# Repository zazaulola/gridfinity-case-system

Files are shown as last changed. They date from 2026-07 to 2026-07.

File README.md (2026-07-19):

# Gridfinity Case System

A fork of [smkent/monoscad](https://github.com/smkent/monoscad) focused on
the [Gridfinity Rugged Storage Box](gridfinity/rugged-box/): a stackable,
latching, parametric OpenSCAD case system for Gridfinity bins, extended
into a complete carry system rated for **~5 kg per case and 15-25 kg per
stack**.

Demo animation

*One-turn overview → lid opens → two layers of bins and a removable level
tray go in → a second case stacks below and locks → the split lid handle
rises into its self-clamping X-arch and lifts the stack.*

## Fork additions

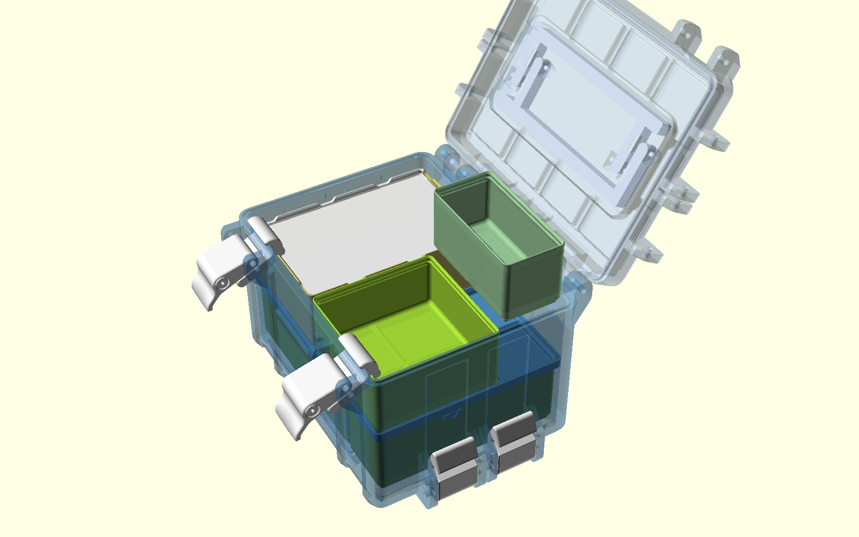
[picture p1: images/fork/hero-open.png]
Open case with bins


* **Lid carry handle** recessed into the center of the lid — folded, it
  stays below the stacking plane, so cases still stack and latch on top.
  Two styles: a single fold-flat bail, or the **split X-arch** (two
  identical half-bails on central axes whose grip bars press together
  under load; four pivots, level carry on every case size).
* **Heavy-duty attachments**: M4 screws with enlarged eyelets and latch
  bodies, a third hinge from 3 units wide, and optional stacking latches
  at every grid boundary.
* **Removable level tray**: a baseplate tray with Gridfinity feet that
  turns bin layers into liftable levels; fold-flat pull bails hide below
  the bin seating plane, all-printed pivots.
* **Hardware-friendly options**: hex nut pockets (screws clamp with nuts,
  no thread-forming); **axle sleeves** — printed 8 mm bearing sleeves
  retained by two short M4x12..20 screws, so no screws longer than 20 mm
  are needed anywhere and rotating parts never ride on threads.
* **Silicone cord seal**: a dovetail groove in the bottom lip for 2-4 mm
  cord, with snap-in retention and self-limited ~25% compression.
* **Bins**: plain stackable bins and sliding-lid bins (from
  [gridfinity/lid-bins](gridfinity/lid-bins/)) compose with the cases;
  equal-height bins act as a baseplate for the next layer.

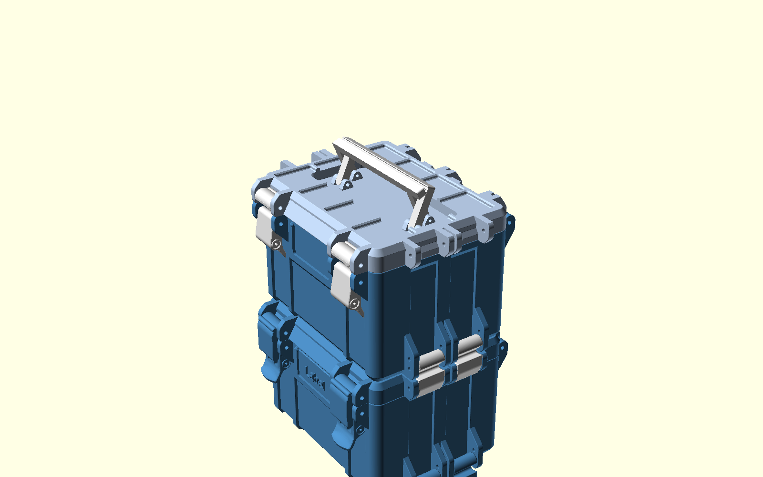
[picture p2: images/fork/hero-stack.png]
Stacked cases with raised handle

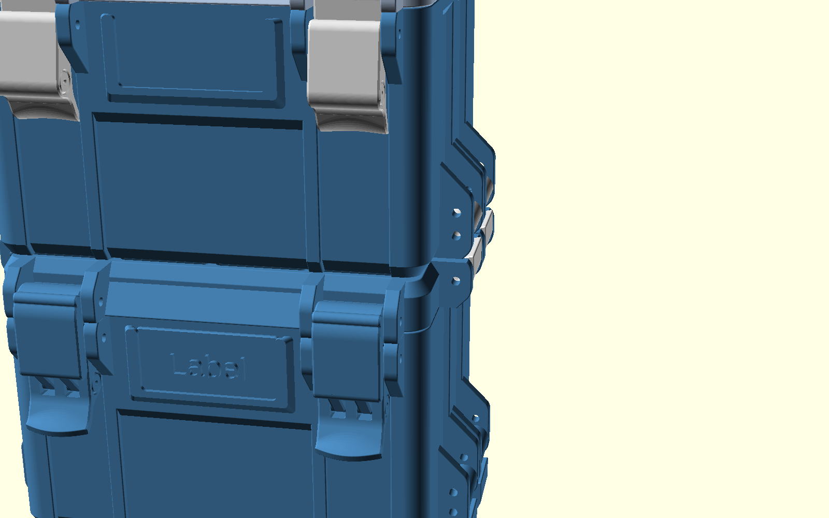
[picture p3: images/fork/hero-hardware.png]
Stacking hardware


See [gridfinity/rugged-box/README.md](gridfinity/rugged-box/README.md) for
option documentation, load-path rationale, hardware lists, and print
guidance. A full pre-rendered STL kit for 260mm printers (5x5 case, 90
bins, 90 lidded bins, level tray) is generated under
`gridfinity/rugged-box/build/` (see the manifest there; the video is
`images/fork/demo.mp4`).

---

# My OpenSCAD models for 3D printing

[bulbasaur0 on Printables][printables-profile]

A monorepository for my [OpenSCAD][openscad] models and remixes. Print-ready
models are also [published on Printables][printables-profile].

## Setup

Models in this repository depend on various
[third-party libraries][openscad-libraries], which are provided as
[git submodules][git-submodules] using
[smkent/openscad-libraries][smkent-openscad-libraries].

After cloning this repository, install all third-party libraries by running in
the repository directory:

```console
git submodule update --init --recursive
```

## Rendering models via CLI

Each model has preconfigured renders to be created via the
[OpenSCAD CLI][openscad-cli] using [SCons][scons].
Model STL files published to Printables are rendered this way.

SCons is a Python package and can be installed using `pip`:

```console
pip install --user scons
```

To build the configured model renders for a particular model, change to the
desired model directory and run:

```console
scons -u
```

Rendered models will be placed in a `build` subdirectory within the model
directory.

## Model samples

Click an image to view the corresponding model, or browse subdirectories for all
models.

Gridfinity Rugged Storage Box, Parametric and Customizable
Rugged Storage Box
Gridfinity Bins with Lids (parametric remix)
Segmented Modular Hose
Drill bit clips for Bosch Custom Case / Pick and Click
SG-1 Stargate

## License

### Models

Each model in this repository is licensed individually, especially for remixes
which must maintain compatible licensing with their original model(s).

See `README.md` and/or any `LICENSE` files within a model's subdirectory for
that model's license.

### Third party libraries

Third party libraries have their own licenses.

### Monorepository

All remaining contents of this repository (i.e. not models or third party
libraries) are licensed under [Creative Commons (4.0 International License)
Attribution][license-cc-by-4.0].

[git-submodules]: https://git-scm.com/book/en/v2/Git-Tools-Submodules
[license-cc-by-4.0]: http://creativecommons.org/licenses/by/4.0/
[openscad-cli]: https://en.wikibooks.org/wiki/OpenSCAD_User_Manual/Using_OpenSCAD_in_a_command_line_environment
[openscad-libraries]: https://en.wikibooks.org/wiki/OpenSCAD_User_Manual/Libraries
[openscad]: https://openscad.org
[printables-profile-badge]: /_static/printables-profile-badge.svg
[printables-profile]: https://www.printables.com/@bulbasaur0/models
[scons]: https://scons.org/
[smkent-openscad-libraries]: https://github.com/smkent/openscad-libraries

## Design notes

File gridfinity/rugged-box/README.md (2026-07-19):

# Gridfinity Rugged Storage Box, Parametric and Customizable

[Available on Printables][printables-model]
[CC-BY-SA-4.0 license][license]

A Gridfinity compatible parametric and customizable rugged storage box or
toolbox for OpenSCAD. Make and customize your own boxes!

Renders animation showing various box sizes

# Description

My [Rugged Storage Box][rugged-box-base-model], now for [Gridfinity][gridfinity]
bins!

Inspired by
[several][rugged-gridfinity-box-by-pjotrstrong]
[other][gridfinity-storage-box-by-pred]
[terrific][gridbox-by-bilbodd]
[Gridfinity][fully-printable-gridfinity-box-by-lennard-hoting]
[box][rugged-gridfinity-box-by-peterdesigns]
[models][rugged-gridfinity-box-lid-insert-by-zanfar],
I built a Gridfinity rugged box model of my own! This is a parametric model
which can create boxes of any size. I chose [OpenSCAD][openscad] so the software
and model would be fully open source.

## Features

Photo of stacked boxes
Photo of open boxes

Photo of open box with lid plate caption
Photo of box side with latch captions

Clip of box opening/closing
Clip of box stacking latches usage

Gridfinity:

* Configurable sizing in Gridfinity grid units
* Optional exterior stacking grid on top/bottom of box

Box options:

* Choice of latch style (clip or draw)
* Side stacking latches
* Optional handle
* Optional label
* Top opening grip and hinge end stops
* Lip seal: integrated, for 1.75mm filament, or a dovetail groove for
  silicone cord (fork addition)
* Reinforced (thicker) corners
* Optional third hinge for large boxes

## Fork additions: lid carry handle and heavy-duty attachments

This fork extends the original model with a stack-friendly carry handle in
the lid and reinforced attachments, targeting transport of a stack of loaded
boxes (up to ~5 kg per box, ~15-25 kg per stack of 3-5 boxes) carried by the
top box's lid handle.

### Lid carry handle (`Lid_Handle`, default on)

A fold-flat carry bail recessed into a pocket in the center of the lid:

* The folded bail and its pivot bosses stay at least 1 mm below the plane of
  the Gridfinity feet of a box stacked on top, so **boxes still stack and
  latch normally with the handle installed**.
* The pivot axis is a pair of **M3x20** screws in double shear through
  printed bosses, so the carrying load is carried by steel, not by printed
  hinge pins. The lid handle always uses M3 pivots regardless of the
  `Heavy_Duty` setting.
* A sloped finger scoop ahead of the folded grip bar provides access to lift
  the bail; when raised, there is ~32 mm of finger clearance between the
  grip and the lid surface.
* Requires a box at least 3 Gridfinity units wide and a top at least
  2 units tall. On boxes 2-3 units long the pivot axis is offset from the
  lid center (the pocket cannot be centered around it; ~29 mm at 2 units,
  ~8 mm at 3 units), so a single box hangs with a slight tilt; stacks hang
  nearly level. On boxes 4+ units long the axis is centered and the box
  hangs level.
* Print the `lid_handle` part flat as oriented; layers run along the bail
  plane, which loads the layer lines in tension/bending within the plane.
* Assembly: place the bail eyelets between the boss pairs and drive the two
  M3x20 screws outward from the pocket center with a long (ball-end) hex
  key. The screws thread into the outer bosses.

The handle load path is: bail (steel pivot screws) → lid pocket housing →
lid hinges and latches → box body → side stacking latches → next box below.
The weakest links are the printed latch and hinge parts, which is what the
heavy-duty option reinforces.

#### Split style (`Lid_Handle_Style` = "split")

An alternative handle: two point-symmetric half-bails (the same printed
part twice) on parallel axes 18 mm apart at the lid center. They fold
inward past each other — the arms are interleaved into separate lanes —
and rise to a **self-clamping X-arch**: under load, arm tension presses
the two grip bars together, so the arch needs no latch. Compared to the
single bail:

* Four M3 pivots share the carry load (half the per-pivot cyclic load).
* The pocket is symmetric and shorter (~63 mm vs ~72 mm) and 1 mm
  shallower, preserving more of the lid stacking grid.
* The pivot axes are centered on every box size, so a carried box hangs
  level even at 2 units long (the single bail is offset there).
* No finger scoop: raise the handle by dragging both textured bars
  toward the center with two fingertips, then grip the met pair
  (~27 mm above the lid; fingers curl into the arch and the open pocket).
* Hardware: 4x M3x18..20.

### Heavy-duty attachments (`Heavy_Duty`, default on)

* All hinge, latch, and stacking latch screws move from **M3 to M4**, and
  the printed screw eyelets and latch bodies scale up accordingly
  (`screw_eyelet_size_proportion` and `latch_body_size_proportion`
  3.0 → 3.4). Latches hook over the exposed steel screw shanks, so shear
  goes through steel; the enlarged printed eyelets reduce bearing stress at
  roughly 5 MPa or less per attachment at the target loads (PETG yields at
  ~50 MPa; short-term carrying loads leave a comfortable margin for creep
  and shock).
* The optional third (center) hinge now engages on boxes **3+ units wide**
  (previously 5+).
* With the default `Latch_Width` 28 and `Rib_Width` 6, attachment screws are
  **M4x40** (`28 + 2 * 6 = 40`); check the console output (BOM echo) for the
  exact count and length for your configuration. Set `Heavy_Duty` to false
  to keep the original M3 sizing.
* For even thicker ribs, raise `Rib_Width` together with `Latch_Width`: the
  paired top hinge requires `Latch_Width > 4 * Rib_Width + 0.6` (for
  example, `Rib_Width` 8 with `Latch_Width` 34 and M4x50 screws). Raising
  `Rib_Width` alone silently degrades the top hinge to a single narrow
  eyelet.

### Hex nut pockets (`Nut_Pockets`, default off)

Cuts DIN 934 hex nut pockets into the outward faces of the attachment ribs
(latches, stacking latches, and both outer faces of the bottom hinge ribs)
and enlarges every attachment screw hole to clearance fit. One nut per
screw. Benefits:

* Hinge screws become nut-clamped hinge pins: opening and closing the lid
  cannot rotate or back the screw out of formed plastic threads. (Without
  this option the tight fit in the bottom hinge ribs is intentional — the
  screw thread-forms there and stays fixed while the lid's loose eyelet
  rotates on the shank; if your printed lid eyelet is also tight, ream it
  to ~4.2-4.5 mm for M4.)
* Threads no longer wear with repeated disassembly.
* Cut lengths of M4 threaded rod can substitute for screws.

Cap screw heads (7 mm across) partially recess into the pockets on the
head side as a bonus. Nut pockets and screw length: the stock length still
works — the nut sits inside the pocket flush with the rib face.

### Axle sleeves: short common screws only (`Axle_Sleeves`, default off)

Replaces every long M4x40 through screw with a printed **8 mm bearing
sleeve** spanning between the attachment ribs, retained by two short
**M4x12..20** screws driven into its bore from the rib outer faces —
lengths every hardware kit already contains. Benefits:

* No screws longer than 20 mm anywhere in the box (the lid handle already
  uses M3x20 and the level tray is all-printed).
* Latches and hinges rotate on the smooth sleeve surface instead of screw
  threads: far larger bearing area, no thread abrasion of the plastic
  bores, and the sleeve is a cheap replaceable wear part.
* An 8 mm round brass standoff with M4 threads (female-female) is a
  drop-in metal substitute for the printed sleeve.

Print the `axle_sleeve` part set (sleeve counts and both lengths are
echoed to the console). Latch, stacking latch, hinge, and handle bores
grow to ride the sleeve, so render **all** parts with the option enabled —
sleeve-mode latches do not fit a non-sleeve box. Requires `Heavy_Duty`
(M4 sizing); the front `Handle` option still uses long screws.

### Silicone cord seal (`Lip_Seal_Type` = "silicone")

A dovetail cord groove in the bottom lip for standard silicone cord
(`Silicone_Cord_Diameter` 2..4 mm, default 3):

* Groove depth is 0.75x the cord diameter, so the flat top lip compresses
  the cord by up to ~25% at full closure, self-limited by lip contact.
* The dovetail mouth (0.95x cord) snaps the cord in and retains it when
  the box is open; the groove cross-section exceeds the cord area so the
  incompressible silicone has room to spread.
* Use **soft** cord (40..60 ShA); harder cord raises the latch closing
  force noticeably on large boxes. The required cord length is echoed to
  the console (BOM). Join the ends with a straight butt cut and a drop of
  cyanoacrylate, placed mid-wall on the hinge side.
* The top part is unchanged — the option only alters the bottom, and
  works with any other option combination.

### Stacking latch density (`Stacking_Latch_Density`)

For heavy stacks, `max` places one stacking latch at every interior
Gridfinity cell boundary on each side (a 4-unit-long box gets 3 per side
instead of 2). These positions are a superset of the standard ones, so
boxes with mixed density settings still latch to each other when
grid-aligned; for boxes 2-3 units long, `max` equals `standard`. This
option requires `Latch_Width + 2 * Rib_Width` ≤ 40 mm (satisfied by the
defaults, 28 + 2 × 6 = 40) so adjacent latches do not overlap. The default
`standard` keeps the original placement.

### Other default changes in this fork

* The front `Handle` option now defaults to **false** (the lid handle is the
  primary carry); enable it in the customizer if you want both.
* `Third_Hinge` and `Lid_Handle` default to true, `Heavy_Duty` defaults to
  true.

### Removable level tray (`level-tray.scad`)

A companion model: a removable tray whose top face copies the box floor
baseplate and whose underside has Gridfinity feet, so it registers on the
box floor or on a layer of equal-height bins — building removable levels
of bins inside the box. Two fold-flat pull bails recessed into deepened
wells at two edge cells allow lifting the whole level out; folded, the
bails stay below the bin seating plane, so every cell remains usable
(remove the two bins over the wells to raise the bails). Fully printed:
the bails pivot on printed 3 mm axle pins inserted from the tray edge
faces; inside the box, the box walls keep the pins captive. Set `Width`
and `Length` to the box size; parts: `tray`, `pull_bail` (x2),
`axle_pin` (x2).

### Print recommendations for load-rated boxes

* Material: PETG or ASA (better creep and impact behavior than PLA;
  PLA is acceptable for light duty).
* Walls: 4+ perimeters; infill 30%+ (gyroid or grid).
* Use the `top_modifier`/`bottom_modifier` volumes to locally raise infill
  and perimeters around the attachment ribs (see "Reinforcing the box
  attachment ribs" below). The lid handle pocket housing is included in the
  top modifier volume.
* Latches, stacking latches, and the lid handle print in their default
  orientation; do not rotate them, their strength depends on layer
  direction.

## Hardware and Tools

**Fork note:** with this fork's default `Heavy_Duty = true`, the hinges and
latches use **M4** screws — **M4x40** hex socket head cap screws (DIN 912)
at the default `Latch_Width` 28 / `Rib_Width` 6, driven with a 3 mm hex key.
The lid handle additionally takes 2x **M3x20**. The console output (BOM
echo) prints the exact screw count and length for your configuration. The
rest of this section describes the original M3 sizing, which applies when
`Heavy_Duty` is false.

The hinges and latches are attached using M3 screws, **M3x40** by default.
Depending on whether a handle or stacking latches are desired, a box may take
between 6 and 25 screws to assemble.

My boxes are assembled using M3x40 and M3x55 hex socket head cap screws
(DIN 912):

* M3x40 ([AliExpress 1][m3x40-aliexpress-1], [AliExpress 2][m3x40-aliexpress-2],
  [Amazon][m3x40-amazon], [Trimcraft Aviation RC][m3x40-trimcraftaviationrc])
* M3x55 ([AliExpress][m3x55-aliexpress], [Amazon][m3x55-amazon])
  -- if attaching the optional handle

To assemble boxes with three stacking latches per side and/or a third hinge, a
hex allen key matching your screws is needed since a drill/driver won't fit. M3
hex socket head cap screws use 2.5mm drive, so a ~6" 2.5mm hex allen key is
needed for these
([Home Depot][2.5mm-hex-allen-key-hd], [Amazon][2.5mm-hex-allen-key-amazon]).

### Screw length formula

* All screws except for boxes with handles:
  * `Latch Width` (default 28mm) + 2 x `Rib Width` (default 6mm).
    At default values, `28 + 2 * 6 = 40`, or M3x40 screws.
  * To use M3x30 screws, set `Latch Width` to 22 and `Rib Width` to 4.

* For boxes with handles, replace two of the above screws with:
  * `Latch Width` (default 28mm) + 3 x `Rib Width` (default 6mm) + handle
    thickness (10mm).
    At default values, `28 + 3 * 6 + 10 = 56`, or about M3x55 screws.

## Rendering

### OpenSCAD version and configuration

Two OpenSCAD options are available which greatly improve rendering speed, but
are currently only in the development snapshots. You can download a development
snapshot from [the OpenSCAD downloads page][openscad-download] (scroll down
about half way).

After installation, open **Edit** > **Preferences**, and in **Features**,
enable:

* fast-csg
* fast-csg-safer
* manifold

OpenSCAD features screenshot

### Model setup

See [the top-level README.md](/README.md) for libraries installation.

### Model rendering

Ensure both `rugged-box-gridfinity.scad` and `rugged-box-library.scad` are
placed in the same directory. Open `rugged-box-gridfinity.scad` in OpenSCAD.

Select your desired dimensions and options in the OpenSCAD Customizer. Then, one
at a time, select each part (top, bottom, latch, stacking latch, handle, lid
handle) in the
Part drop-down. For each part, perform a render (F6) and export to STL (F7).

Customizer screenshot
Customizer part selection screenshot

### Recommended model configuration

*tl;dr:*

* Box parts with different **Gridfinity Stackable** settings are not compatible.
  Print all your box parts with this value enabled or disabled, not a mix of
  both.
* Set **Top Height** to 2
* Set **Bottom Height** to 4, 7, or 10 for a 6, 9, or 12 Gridfinity unit tall
  box, respectively
* To use stacking latches, boxes must have the same **Width** and a multiple of
  2 for **Length**
* Use **draw** latches for boxes 9 or more units tall, or **clip** latches for
  shorter boxes

Boxes with the **Gridfinity Stackable** option modify the placement of the
internal Gridfinity baseplate and top bases to accomodate the exterior stacking
base and baseplate. Therefore both the top and bottom of the box must be printed
with the same value for this option; do not mix and match. Additionally,
stacking latches will not reach the correct height between the two types of
boxes.

I recommend keeping most of the box height in the bottom, so Gridfinity bins
will be more contained in the box when the lid is open. I render my box tops
with **Top Height** set to **2** (7mm Gridfinity units).

Most of my Gridfinity bins are multiples of 3 units high (e.g. 3 or 6). I
therefore like to print boxes that are multiples of 3 units high. For a total
box height at a multiple of 3, I set **Bottom Height** to the desired box height
minus my **Top Height** of 2. For example, to make a box that is 9 total
Gridfinity units tall, I set **Top Height** to **2** and **Bottom Height** to
**7**.

If using the stacking latches feature, boxes will stack if they are the same
**Width** (left to right) and have stacking latch attachments at consistent lengths
on the side. To produce boxes with consistent attachment points, set **Length**
(front to back) to a multiple of 2 Gridfinity units. For example, a 6 unit wide
and 4 unit long box can use stacking latches with another box of the same size,
or with a 6 unit wide and 6 unit long box.

Front latches: I prefer draw latches but they are taller, so clip latches are also
available. I recommend using draw latches for boxes with a total height of 9
Gridfinity units or more. Smaller boxes should use clip latches.

Larger boxes use more filament, but result in more storage space per amount of
filament and time spent to print.

## Printing

### Printer preparation

These boxes are (usually) large prints. Clean your print bed and ensure it is
reasonably level.

### General print settings

The following instructions are for slicing with PrusaSlicer.

My boxes are printed in PETG at 0.24mm layer height, with 2 perimeters and 20%
adaptive cubic infill. I printed my latches and handle at 0.2mm layer height,
with 3 perimeters and 30% adaptive cubic infill.

Print the box top and bottom parts on their outer faces. Latches print on their
side. For the latches, a brim may be helpful for bed adhesion.

For boxes without exterior Gridfinity stacking (**Gridfinity Stackable** model
option), the box tops and bottoms print without supports.

Slicer screenshot with plain box

For boxes with exterior Gridfinity stacking, see
["Additional print settings for Gridfinity Stackable boxes"](#additional-print-settings-for-gridfinity-stackable-boxes)
below.

#### Reinforcing the box attachment ribs

PrusaSlicer can configure this model to use a higher infill on specific parts,
such as the attachment ribs (where screws are installed). The model includes
optional modifier volumes to make this simple.

To render a modifier volume in the OpenSCAD model, open and configure the box
model the same as the box model you'd like to print. Then, in the **Part**
drop-down, select and render each of:

* Top print modifier volume for attachment ribs
* Bottom print modifier volume for attachment ribs

This will produce a model that is just the attachment ribs without the box body.
Render and export each of these models.

OpenSCAD screenshot of modifier part selected

In PrusaSlicer, load the box model to print. Then, in the Plater view,
right-click on the box model to open the context menu. Select **Add Modifier**
-> **Load...**, and then select the modifier volume for the matching part
(bottom/top). The modifier volume should perfectly overlap with the existing
model.

Finally, locate the added modifier volume model in the right sidebar next to the
Plater view. Right-click on the modifier volume, and select **Infill** to
override the infill settings for that volume. Then, enter your desired infill
percentage for the ribs (e.g. 100%).

Now the model is configured to slice the ribs with 100% infill!

PrusaSlicer modifier steps animation

### Additional print settings for Gridfinity Stackable boxes

Boxes with the **Gridfinity Stackable** model option require supports and
additional settings to print for both the box top and bottom.

#### Box top

The box top prints upside down. Supports are needed for each grid of the
integrated Gridfinity baseplate.

Slicer screenshot of stackable box top

OpenSCAD renders the exterior stacking grid on the box top with some errant
zero-thickness polygons that make manually painting supports difficult. (These
don't affect the printed box.)

With the support painting tool (hotkey **L**):

* Next to the **Highlight overhang by angle** value, click the edit button and
  enter **1**.
* Click **Enforce** to automatically paint supports.

Slicer screenshot of stackable box top, support application

This method paints the integrated Gridfinity baseplate, and additionally the
very top overhang on all the screw holes with supports. The screw hole overhangs
do not need supports, so these should be removed. With the support painting tool
still selected:

* Uncheck **Split triangles** near the bottom of the paint settings. This will
  speed up the manual (un-)painting process
* **Shift+Left-click** on each of the inner screw hole overhang polygons to
  remove the painted supports from the screw holes

Slicer screenshot of stackable box top, supports applied
Slicer screenshot of stackable box top, overhang supports to remove

Finally, configure these print settings for the box top:

* Enable **Support material > Generate support material** (Enable supports)
* Disable **Support material > Auto-generated supports** (Add supports only to
  the painted areas)
* Set **Support material > Style** to **Snug**. Organic supports use more
  material and require longer to print.
* Set **Support material > Pattern spacing** to **5**. This decreases the amount
  of support material used.
* Set **Support material > XY separation between and object and its support** to
  **4**. This ensures a border between the support bases and gridfinity base
  square edges for easier support removal.
* Set **Infill > Bridging angle** to **135**. This sets the first Gridfinity
  baseplate layer visible on the box top to print at an angle, for a better
  finished look. Avoid setting this to 45, as that causes the first and second
  model layers to be printed at the same angle which is undesirable.

Slicer screenshot of stackable box top, ready to print

#### Box bottom

The box bottom prints upright. Supports are needed for the outer perimeter
that overhangs the base Gridfinity grid.

Slicer screenshot of stackable box bottom

With the support painting tool (hotkey **L**):

* Uncheck **Split triangles** near the bottom of the paint settings. This will
  speed up the manual painting process.
* Set **Brush size** to a small value, such as **0.5**. This will make the
  painting process easier.
* Rotate the model so the underside is visible.
* **Left-click** to paint supports on the outer perimeter that overhangs the
  base Gridfinity grid.

Slicer screenshot of stackable box bottom, with painted supports

Finally, configure these print settings for the box bottom:

* Enable **Support material > Generate support material** (Enable supports)
* Disable **Support material > Auto-generated supports** (Add supports only to
  the painted areas)
* Set **Support material > Style** to **Snug**. Organic supports use more
  material and require longer to print.
* Set **Support material > Pattern angle** to **45** (or 135). By default, snug
  supports print in straight horizontal lines which would result in very long
  single lines drawn around two of the box sides. Setting this to 45 or 135
  causes the support pattern to be properly staggered around the entire box.
* Set **Infill > Bridging angle** to **135**. This sets the first box body layer
  on the underside of the main box body to print at an angle, for a better
  finished look. Avoid setting this to 45, as that causes the first and parts of
  the second model layers to be printed at the same angle which is undesirable.

If you are reconfiguring your slicer after preparing the box top, restore these
settings to their default values:

* **Support material > Pattern spacing** (default 2mm).
* **Support material > XY separation between and object and its support**
  (default 60%).

Slicer screenshot of stackable box bottom, ready to print

## Assembly

**Important**: Don't overdrive the screws into the screw holes. They just need
to be attached to fasten the hinges and latches, and for the latches to clip on
to when the box is closed.

Place the box top onto the box bottom, and install screws into the hinges.

Attach the front and side stacking latches with additional screws. If attaching
a handle to the front, use two longer screws for the front latch screw on the
bottom in order to attach the handle.

**Note**: For large boxes with a three stacking latches per side and/or the
optional third hinge, install the center hinge/latch screws first with a hex
allen key before installing the remaining hinge/latch screws.

Photo of middle hinge/latch screw installation

## Enjoy!

I had a lot of fun creating this model. Please share your feedback and makes!

## Differences of the remix compared to the original

This uses [Gridfinity Rebuilt in OpenSCAD][gridfinity-rebuilt-openscad] to add
[Gridfinity][gridfinity]-compatible baseplates and stacking covers to my
[Rugged Storage Box][rugged-box-base-model].

## Attribution and License

This model is licensed under [Creative Commons (4.0 International License) Attribution-ShareAlike][license].

This is a remix of
[**Gridfinity Rebuilt in OpenSCAD** by **kennetek**][gridfinity-rebuilt-openscad].

[Gridfinity][gridfinity] and
[Gridfinity Rebuilt in OpenSCAD][gridfinity-rebuilt-openscad]
use the [MIT License][gridfinity-license].

[2.5mm-hex-allen-key-amazon]: https://amazon.com/dp/B005G2RMLM
[2.5mm-hex-allen-key-hd]: https://www.homedepot.com/p/203195203
[fully-printable-gridfinity-box-by-lennard-hoting]: https://www.printables.com/model/369813-fully-printable-gridfinity-box-parametric
[gridbox-by-bilbodd]: https://www.printables.com/model/325677-gridbox
[gridfinity-license]: LICENSE.gridfinity
[gridfinity-rebuilt-openscad]: https://github.com/kennetek/gridfinity-rebuilt-openscad
[gridfinity-storage-box-by-pred]: https://www.printables.com/model/543553-gridfinity-storage-box-by-pred-now-parametric
[gridfinity]: https://www.youtube.com/watch?v=ra_9zU-mnl8
[license-badge]: /_static/license-badge-cc-by-sa-4.0.svg
[license]: http://creativecommons.org/licenses/by-sa/4.0/
[m3x40-aliexpress-1]: https://www.aliexpress.us/item/3256805665122576.html
[m3x40-aliexpress-2]: https://www.aliexpress.us/item/2251832624557792.html
[m3x40-amazon]: https://amazon.com/dp/B0CFQN9P7Y/
[m3x40-trimcraftaviationrc]: https://www.trimcraftaviationrc.com/index.php?route=product/product&product_id=481
[m3x55-aliexpress]: https://www.aliexpress.us/item/3256802885431338.html
[m3x55-amazon]: https://amazon.com/dp/B0BGM9N73R/
[openscad-download]: https://openscad.org/downloads.html
[openscad]: https://openscad.org
[printables-badge]: /_static/printables-badge.png
[printables-model]: https://www.printables.com/model/757297
[rugged-box-base-model]: ../../rugged-box/
[rugged-gridfinity-box-by-peterdesigns]: https://www.printables.com/model/495142-rugged-gridfinity-box-parametric
[rugged-gridfinity-box-by-pjotrstrong]: https://www.printables.com/model/361829-rugged-gridfinity-box
[rugged-gridfinity-box-lid-insert-by-zanfar]: https://www.printables.com/model/491142-rugged-gridfinity-box-lid-insert

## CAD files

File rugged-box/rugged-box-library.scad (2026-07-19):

/*
 * Customizable and Parametric Rugged Storage Box
 * By smkent (GitHub) / bulbasaur0 (Printables)
 *
 * Rugged storage box library
 *
 * Licensed under Creative Commons (4.0 International License) Attribution-ShareAlike
 */

module __end_customizer_options__() { }

// Constants

$fa = $preview ? $fa : 2;
$fs = $preview ? $fs / 2 : 0.2;

// Attachment screw diameter
screw_diameter = 3; // M3

// Decrease screw hole diameter just slightly for better thread-forming fit
screw_hole_diameter_size_tolerance = -0.1;

// Hex nut pocket fit added to the nut width across flats
nut_pocket_width_tolerance = 0.35;
// Extra pocket depth beyond the nut height
nut_pocket_depth_tolerance = 0.4;

// Axle sleeve outer diameter: a printed (or brass standoff) bearing sleeve
// spanning between the attachment ribs. Rotating parts ride the smooth
// sleeve surface, and the sleeve is retained by two short screws driven
// into its bore from the rib outer faces, replacing the long through screw
axle_sleeve_diameter = 8;
// Diametral running fit for parts rotating on the sleeve
axle_sleeve_fit = 0.4;
// Snug fit for latch catch slots hooking over the sleeve
axle_sleeve_catch_fit = 0.2;

// Widen angle of box plain ribs
plain_ribs_angle = 8;

// Extra space between box body and hinge for clearance
hinge_extra_setback = 0.2; // [0:0.1:2]
hinge_size_tolerance = 0.1;

// Box top hinge screw eyelet position fit tolerance adjustment
top_hinge_eyelet_position_tolerance = 0.1;

// Screw eyelet diameter as a proportion of screw diameter
screw_eyelet_size_proportion = 3.0; // [1.5:0.1:5]

// Depth and maximum width of lip grip
top_grip_depth = 6;
top_grip_width = 100;

// Latch size
latch_edge_radius = 0.8;
latch_body_size_proportion = 3.0; // [1.5:0.1:5]

// Stacking latch size
stacking_latch_catch_offset = -10;
stacking_latch_grip_length = 8;
stacking_latch_screw_separation = 20;

// Handle size
handle_thickness = 10;
handle_min_height = 16;
handle_max_height = 35;
handle_radius = 5;

// Lid handle size
// The lid handle pivots always use M3 screws, independent of the main
// attachment screw size, so the folded handle stays below the stacking plane
lid_handle_screw_diameter = 3;
lid_handle_screw_length = 20;
lid_handle_eyelet_size_proportion = 3.0;
// Local hole fit so overrides of the main screw_diameter (heavy-duty M4)
// cannot change the lid handle pivot fits
lid_handle_screw_hole_fit = lid_handle_screw_diameter * 0.2;
lid_handle_bar_thickness = 9;
lid_handle_bar_width = 16;
lid_handle_bar_max_length = 130;
lid_handle_bar_edge_radius = 3;
lid_handle_arm_width = 8;
lid_handle_boss_width = 6;
lid_handle_min_grip_span = 60;
// Finger space between the raised grip bar underside and the lid surface
lid_handle_grip_clearance = 32;
// Distance from the pocket to the box interior edge
lid_handle_pocket_rim = 8;
lid_handle_pocket_wall = 4;
lid_handle_pocket_corner_radius = 6;
lid_handle_floor_thickness = 3;
// Interior clearance kept below the pocket housing for bin lips
lid_handle_interior_margin = 3.5;
// Extra pocket length ahead of the folded grip bar for finger access
lid_handle_finger_room = 8;
// Slope inset of the finger scoop wall between pocket opening and floor
lid_handle_scoop_inset = 6;
lid_handle_swing_margin = 2;
lid_handle_fit = 0.4;

// Split lid handle: two point-symmetric half-bails on parallel central
// axes, folding inward past each other (arms interleaved along X) and
// rising to a self-clamping X-arch whose grip bars press together under
// load. Four pivots halve the per-pivot load; the pocket is symmetric
// and shorter than the single bail's, and the box hangs level on every
// box size.
split_handle_eyelet_radius = 4.0;
split_handle_bar_thickness = 8;
split_handle_bar_width = 8;
split_handle_arm_width = 8;
// Axis offset from the lid center
split_handle_axis_offset = 9;
// Axis-to-bar-center arm length
split_handle_arm_length = 34;
// Inboard shift of each half's inner arm, creating the interleave slots
split_handle_arm_slot = 11;
split_handle_boss_width = 5;
split_handle_screw_length = 20;

// Label size
label_thickness = 2;
label_fit_thickness = 0.1;
label_text_thickness = 2.0;
label_holder_inset = 5;
label_holder_lip = 2;
label_holder_thickness = 2 + label_thickness + label_fit_thickness;
label_max_height = 30;

// Public modules

/*
 * Setup module
 *
 * Use this module to configure box sizing and features before rendering a part
 *
 * Arguments:
 *  - width: Interior side-to-side size
 *  - length: Interior front-to-back size
 *  - top_height: Interior top height
 *  - bottom_height: Interior bottom height
 *  - corner_radius: Interior corner radius (Reduces interior storage space)
 *  - edge_chamfer_proportion: Proportion of corner_radius to chamfer outer
 *    top/bottom edges (Reduces interior storage space)
 *  - lip_seal_type: Type of shape of seal to use, if desired:
 *      - "none": No seal
 *      - "wedge": Wedge-shaped seal
 *      - "square": Square-shaped seal
 *      - "filament-1.75mm": Seal cutout on both top and bottom for
 *          1.75mm filament
 *      - "silicone": Dovetail groove in the bottom lip for silicone
 *          cord of seal_cord_diameter; the flat top lip compresses the
 *          cord by up to ~25% and the undercut retains it when open
 *  - seal_cord_diameter: Silicone cord diameter in millimeters for the
 *    "silicone" seal type
 *  - reinforced_corners: Make the corners as thick as the box lip
 *  - latch_type: Style of front latches: "clip" or "draw"
 *  - latch_count: Number of latches (1 or 2). The default of 0 determines the
 *    number of latches automatically.
 *  - top_grip: Add optional grip to front of box top
 *  - hinge_end_stops: Add optional hinge end stops to box bottom hinges
 *  - handle: Add optional handle for sufficiently wide boxes
 *  - nut_pockets: Cut hex nut pockets into the outward faces of the
 *    attachment ribs and enlarge all attachment screw holes to clearance
 *    fit. Screws then clamp with nuts instead of thread-forming into the
 *    plastic: no thread wear, no screw rotation in use, and cut threaded
 *    rod can substitute for screws.
 *  - axle_sleeves: Replace every long through screw with a printed
 *    bearing sleeve spanning between the attachment ribs, retained by two
 *    short screws (M4x12..20) driven into the sleeve bore from the rib
 *    outer faces. Rotating parts ride the smooth sleeve surface instead
 *    of screw threads. Latch, stacking latch, hinge, and handle bores
 *    grow to the sleeve diameter. Requires M4 attachment sizing.
 *  - lid_handle: Add optional fold-flat carry handle recessed into the
 *    center of the box top for sufficiently large boxes
 *  - lid_handle_style: "bail" for a single fold-flat bail, or "split" for
 *    two point-symmetric half-bails on parallel central axes that fold
 *    inward past each other and rise to a self-clamping X-arch. The split
 *    style has a shorter symmetric pocket, four pivots sharing the load,
 *    and hangs level on every box size.
 *  - lid_handle_stow_depth: Depth below the box top outer surface at which
 *    the highest point of the folded lid handle rests. Set this deeper than
 *    any exterior stacking features so stacked boxes clear the folded handle.
 *  - label: Add optional label for sufficiently wide boxes
 *  - label_text: Custom text for optional label
 *  - label_text_size: Approximate label text size in millimeters
 *
 * Example:
 *
 *      box(width=100, length=50, top_height=15, bottom_height=30) {
 *          // Render box top
 *          translate([120, 0, 0])
 *          rbox_top();
 *
 *          // Render box bottom
 *          rbox_bottom();
 *      }
 */
module rbox(
    width,
    length,
    bottom_height=0,
    top_height=0,
    corner_radius=5,
    edge_chamfer_proportion=0.4,
    lip_seal_type="wedge",
    seal_cord_diameter=3.0,
    reinforced_corners=false,
    latch_type="draw",
    latch_count=0,
    top_grip=false,
    hinge_end_stops=false,
    handle=false,
    nut_pockets=false,
    axle_sleeves=false,
    lid_handle=false,
    lid_handle_style="bail",
    lid_handle_stow_depth=1.0,
    label=false,
    label_text="",
    label_text_size=10
) {
    // Set base dimensions
    $b_inner_width = width;
    $b_inner_length = length;
    $b_top_inner_height = top_height;
    $b_bottom_inner_height = bottom_height;
    $b_corner_radius = corner_radius;
    $b_edge_chamfer_proportion = edge_chamfer_proportion;
    $b_lip_seal_type = lip_seal_type;
    $b_seal_cord_diameter = seal_cord_diameter;
    $b_reinforced_corners = reinforced_corners;
    $b_latch_type = latch_type;
    $b_latch_count = latch_count;
    $b_top_grip = top_grip;
    assert(
        !axle_sleeves || screw_diameter >= 4,
        str(
            "Axle sleeves require M4 attachment sizing (screw_diameter ",
            screw_diameter, " is too small for the latch bores)"
        )
    );
    $b_hinge_end_stops = hinge_end_stops;
    $b_handle = handle;
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

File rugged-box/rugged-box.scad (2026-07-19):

/*
 * Customizable and Parametric Rugged Storage Box
 * By smkent (GitHub) / bulbasaur0 (Printables)
 *
 * Parametric rugged storage box model
 *
 * Licensed under Creative Commons (4.0 International License) Attribution-ShareAlike
 */

include <rugged-box-library.scad>;

/* [Rendering] */
// Part selection. Note: Assembled box previews show latches without chamfers for performance reasons.
Part = "assembled_open"; // ["bottom": Bottom, "top": Top, "latch": Latch, "stacking_latch": Stacking latch, "handle": Handle, "lid_handle": Lid carry handle, "axle_sleeve": Axle sleeve set, "label": Label, "side-by-side": Top and Bottom side-by-side, "assembled_open": Assembled open, "assembled_closed": Assembled closed, "bottom_modifier": Bottom print modifier volume for attachment ribs, "top_modifier": Top print modifier volume for attachment ribs]

/* [Dimensions] */
// All units in millimeters

// Interior side-to-side size in millimeters
Width = 120; // [20:1:300]

// Interior front-to-back size in millimeters
Length = 60; // [20:1:300]

// Interior bottom height in millimeters
Bottom_Height = 25; // [0:1:300]

// Interior top height in millimeters
Top_Height = 7; // [0:1:300]

// Interior corner radius in millimeters. Reduces interior storage space.
Corner_Radius = 5; // [0:0.1:20]

// Proportion of Corner Radius to chamfer outer top and bottom edges. Reduces interior storage space.
Edge_Chamfer_Proportion = 0.4; // [0:0.1:1]

/* [Features] */
// Type or shape of seal to use, if desired
Lip_Seal_Type = "wedge"; // [none: None, wedge: Wedge ▽, square: Square □, "filament-1.75mm": 1.75mm Filament ○, silicone: Silicone cord ●]

// Silicone cord diameter in millimeters, for the silicone seal type. The cord snaps into a dovetail groove in the bottom lip; buy soft cord (40-60 ShA). Cord length is echoed to the console.
Silicone_Cord_Diameter = 3.0; // [2:0.5:4]

// Make the corners as thick as the box lip
Reinforced_Corners = false;

// Add a front grip to the box top (for boxes with two latches)
Top_Grip = false;

// Add end stops to the hinges on the box bottom
Hinge_End_Stops = false;

// Latch style
Latch_Type = "clip"; // [clip: Clip, draw: Draw]

// Optional handle for sufficiently wide boxes
Handle = true;

// Optional fold-flat carry handle recessed into the center of the lid
Lid_Handle = false;

// Cut hex nut pockets into the attachment rib faces; screws clamp with nuts instead of thread-forming into plastic
Nut_Pockets = false;

// Replace long through screws with printed bearing sleeves retained by two short M4x12..20 screws each; requires M4-sized attachments (see the gridfinity variant's Heavy_Duty overrides)
Axle_Sleeves = false;

// Optional label for sufficiently wide boxes
Label = false;

// Custom text for optional label
Label_Text = "Label";

// Approximate height of text for optional label in millimeters
Label_Text_Size = 10; // [5:0.1:25]

/* [Advanced Size Adjustments] */
// Base wall thickness in millimeters for most of the box
Wall_Thickness = 3.0; // [0.4:0.1:10]

// Thickness in millimeters to add to the wall thickness for the box lip
Lip_Thickness = 3.0; // [0.4:0.1:10]

// Base thickness in millimeters of the support ribs. The latch ribs are this thick, while the hinge and side ribs are twice this thick.
Rib_Width = 6; // [1:0.1:20]

// Latch width in millimeters
Latch_Width = 28; // [5:1:50]

// Distance in millimeters between the latch hinge and catch screws which determines the latch vertical size
Latch_Screw_Separation = 20; // [5:1:40]

// Width in millimeters subtracted from latches for fit
Size_Tolerance = 0.20; // [0:0.01:1]

module __end_customizer_options__() { }

// Modules

rbox(
    Width,
    Length,
    Bottom_Height,
    Top_Height,
    corner_radius=Corner_Radius,
    edge_chamfer_proportion=Edge_Chamfer_Proportion,
    lip_seal_type=Lip_Seal_Type,
    seal_cord_diameter=Silicone_Cord_Diameter,
    reinforced_corners=Reinforced_Corners,
    latch_type=Latch_Type,
    top_grip=Top_Grip,
    hinge_end_stops=Hinge_End_Stops,
    handle=Handle,
    nut_pockets=Nut_Pockets,
    axle_sleeves=Axle_Sleeves,
    lid_handle=Lid_Handle,
    label=Label,
    label_text=Label_Text,
    label_text_size=Label_Text_Size
)
rbox_size_adjustments(
    wall_thickness=Wall_Thickness,
    lip_thickness=Lip_Thickness,
    rib_width=Rib_Width,
    latch_width=Latch_Width,
    latch_screw_separation=Latch_Screw_Separation,
    size_tolerance=Size_Tolerance
)
rbox_part(Part);

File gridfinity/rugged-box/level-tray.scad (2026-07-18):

/*
 * Gridfinity Rugged Box Level Tray
 *
 * A removable tray ("level") for the Gridfinity Rugged Box. The top face is
 * a Gridfinity baseplate matching the box floor; the underside has
 * Gridfinity bases, so the tray registers either on the box floor or on a
 * layer of equal-height bins below (adjacent equal-height bins compose into
 * a baseplate).
 *
 * Two fold-flat pull bails are recessed into deepened wells at two edge
 * cells. Folded, each bail rests below the plane of a seated bin's base, so
 * every cell stays usable. To lift the tray out, remove the two bins over
 * the wells, flip the bails up, and pull.
 *
 * Fully printed: each bail pivots on a printed 3mm axle pin inserted
 * through a channel from the nearest tray edge face. Inside the box, the
 * box wall blocks the axle from backing out.
 *
 * Licensed under Creative Commons (4.0 International License)
 * Attribution-ShareAlike
 */

include <gridfinity-rebuilt-openscad/standard.scad>;
use <gridfinity-rebuilt-openscad/gridfinity-rebuilt-baseplate.scad>;

/* [Rendering] */
Part = "assembled"; // [tray: Tray, pull_bail: Pull bail, axle_pin: Axle pin, assembled: Assembled preview]

/* [Dimensions] */
// Tray size in 42mm Gridfinity units, side-to-side (match the box Width)
Width = 5; // [1:1:10]

// Tray size in 42mm Gridfinity units, front-to-back (match the box Length)
Length = 5; // [1:1:10]

/* [Features] */
// Recessed pull bails for lifting the tray out
Pull_Bails = true;

/* [Advanced Size Adjustments] */
// Interior border of the rugged box beyond the grid, in millimeters
Case_Border = 5;

// Size subtracted from the tray outline for fit inside the box
Fit_Clearance = 0.6;

module __end_customizer_options__() { }

// Constants

$fa = $preview ? $fa : 2;
$fs = $preview ? $fs / 2 : 0.25;

// Total tray thickness: feet (h_base) + body above
feet_height = h_base;
body_height = 7;
socket_floor_z = feet_height + 2;

// Relief pockets under each socket so bin base tips can pass the socket
// floor and the bases seat on the tapered profile (open on real minimal
// baseplates, which have no floor)
tip_relief_size = 38;
tip_relief_depth = 0.9;
// Bin base tip plane when seated: h_base below the plate ridge top; the
// ridge top is the baseplate profile height above the socket floor
plate_profile_height = 4.4;
tray_top_z = socket_floor_z + plate_profile_height;
seat_z = tray_top_z - h_base;

// Pull bail sizing (all printed, no hardware)
bail_thickness = 4.4;
bail_arm_width = 6;
bail_arm_length = 25;
bail_grip_width = 8;
bail_total_width = 30;
bail_fit = 0.3;
// Highest point of the folded bail below the seated bin base tip plane
bail_stow_clearance = 0.25;

axle_diameter = 3;
axle_hole_diameter = 3.3;
axle_cap_diameter = 5.6;
axle_cap_thickness = 1.8;

well_size = 34;
well_corner_radius = 3;
// Upper portion of the socket taper preserved above the well
well_taper_keep = 2.5;

// Derived values

tray_width = Width * l_grid + Case_Border - Fit_Clearance;
tray_length = Length * l_grid + Case_Border - Fit_Clearance;
corner_radius = r_base;

bail_stow_top_z = seat_z - bail_stow_clearance;
bail_axis_z = bail_stow_top_z - bail_thickness / 2;
well_floor_z = bail_axis_z - bail_thickness / 2 - 0.25;
// Pivot axis runs along X (toward the near tray edge), offset in Y within
// the well; the bail folds toward +Y
bail_axis_y = -(well_size / 2 - bail_thickness / 2 - 1.5);

// Well cell positions: centers of the two outermost columns (one well
// for single-column trays)
function well_cells() = (
    let (mid = floor(Length / 2))
    Width == 1 ? [[0, mid]] : [[0, mid], [Width - 1, mid]]
);

function cell_center(cell) = [
    (cell[0] - Width / 2 + 0.5) * l_grid,
    (cell[1] - Length / 2 + 0.5) * l_grid
];

function well_outward(cell) = (
    Width == 1 ? -1 : (cell[0] == 0 ? -1 : 1)
);

module tray_bom() {
    if (Pull_Bails) {
        echo(str(
            "Level tray parts: 1 tray, ", len(well_cells()), " pull bails, ",
            len(well_cells()), " axle pins (all printed, no hardware)"
        ));
        echo(str(
            "Level tray: raised bail grip stands ~",
            bail_arm_length + bail_grip_width / 2 - (tray_top_z - bail_axis_z),
            " mm above the tray surface"
        ));
    }
}

// Modules

module tray_outline_shape(expand=0) {
    offset(r=corner_radius + expand)
    square(
        [tray_width - corner_radius * 2, tray_length - corner_radius * 2],
        center=true
    );
}

module tray_body() {
    // Small bottom chamfer eases entry into the box
    hull() {
        translate([0, 0, feet_height + 1])
        linear_extrude(height=body_height - 1)
        tray_outline_shape();
        translate([0, 0, feet_height])
        linear_extrude(height=1)
        offset(delta=-1)
        tray_outline_shape();
    }
}

// One simplified tapered foot: a frustum that seats on the socket chamfers
// like a Gridfinity base. Built from plain primitives so the booleans stay
// clean. The tip stops short of the socket floor; seating happens on the
// chamfer, as with regular bins.
module tray_foot() {
    foot_tip_gap = 0.4;
    hull() {
        translate([0, 0, foot_tip_gap])
        linear_extrude(height=0.01)
        offset(r=3) square(35 - 6, center=true);
        translate([0, 0, feet_height - 0.01])
        linear_extrude(height=0.01)
        offset(r=5) square(41 - 10, center=true);
    }
}

module tray_feet() {
    for (ix = [0:1:Width - 1], iy = [0:1:Length - 1]) {
        translate(concat(cell_center([ix, iy]), [0]))
        tray_foot();
    }
}

// Axle channel backing tabs out to the tray edge under the rim
module tray_well_feet() {
    for (cell = well_cells()) {
        center = cell_center(cell);
        outward = well_outward(cell);
        intersection() {
            translate([
                center[0] + outward * l_grid / 2,
                center[1] + bail_axis_y,
                feet_height / 2 + 0.2
            ])
            cube([l_grid, 12, feet_height - 0.4], center=true);
            linear_extrude(height=feet_height + 0.01)
            tray_outline_shape();
        }
    }
}

// Material to remove so the tray top matches the box floor baseplate
module tray_plate_cut() {
    // The cut is limited to the grid area so the rim outside the plate
    // keeps its full height as a flush deck ring
    render(convexity=4)
    difference() {
        translate([0, 0, socket_floor_z])
        linear_extrude(height=h_base * 2)
        square(
            [Width * l_grid + 0.5, Length * l_grid + 0.5],
            center=true
        );
        translate([0, 0, socket_floor_z])
        gridfinityBaseplate(Width, Length, l_grid, 0, 0, 0, false, 0, 0, 0);
    }
    // Per-cell tip relief below the socket floor
    for (ix = [0:1:Width - 1], iy = [0:1:Length - 1]) {
        translate(concat(cell_center([ix, iy]), [0]))
        translate([0, 0, socket_floor_z - tip_relief_depth])
        linear_extrude(height=tip_relief_depth + 0.01)
        offset(r=well_corner_radius)
        offset(r=-well_corner_radius)
        square(tip_relief_size, center=true);
    }
}

module bail_well_cavity() {
    translate([0, 0, well_floor_z])
    linear_extrude(
        height=socket_floor_z + well_taper_keep - well_floor_z
    )
    offset(r=well_corner_radius)
    offset(r=-well_corner_radius)
    square(well_size, center=true);
}

// Axle channel from the near tray edge face through the well, in tray
// coordinates for the given well cell
module axle_channel(cell) {
    center = cell_center(cell);
    outward = well_outward(cell);
    edge_x = outward * (tray_width / 2);
    inner_x = center[0] - outward * (well_size / 2 + 2);
    translate([edge_x, center[1] + bail_axis_y, bail_axis_z])
    rotate([0, outward * -90, 0]) {
        cylinder(
            h=abs(edge_x - inner_x) + 0.01,
            d=axle_hole_diameter
        );
        // Counterbore for the axle cap, recessed into the edge face
        translate([0, 0, -0.01])
        cylinder(h=axle_cap_thickness + 0.3, d=axle_cap_diameter + 0.4);
    }
}

module tray_wells_cut() {
    for (cell = well_cells()) {
        translate(concat(cell_center(cell), [0]))
        bail_well_cavity();
        axle_channel(cell);
    }
}
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

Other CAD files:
gridfinity/rugged-box/rugged-box-gridfinity.scad

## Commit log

2026-07-09 Add lid carry handle and heavy-duty attachment options
    Gridfinity Rugged Box upgrades for carrying stacks of loaded boxes
    (target ~5 kg per box, ~15-25 kg per stack):
    - Lid carry handle: fold-flat bail recessed into a pocket in the lid
    center. Folded bail and pivot bosses stay below the stacking plane so
    boxes still stack and latch on top. Steel M3x20 pivots in double
    shear, sloped finger scoop, 32 mm raised grip clearance. New
    lid_handle part and Lid_Handle option (library + both customizers).
    - Heavy_Duty option (default on): M4 attachment screws with enlarged
    eyelets and latch bodies via library constant overrides; Rib_Width
    default 8; third hinge threshold lowered to 3 Gridf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
    [rugged-box-gridfinity.scad, rugged-box-library.scad, rugged-box.scad]
2026-07-10 Apply adversarial review fixes
    - Lid handle pivot holes now use a lid-handle-local fit constant so the
    Heavy_Duty M4 override cannot loosen the always-M3 pivots (was 3.8/3.7
    mm, now 3.6/3.5 mm).
    - Shorten the pivot thread hole overshoot into the pocket wall (cap 2.5
    mm instead of 0.5 mm).
    - Revert default Rib_Width to 6: Rib_Width 8 with Latch_Width 28
    silently degraded the box top hinge to the single-module fallback
    (paired hinge requires Latch_Width > 4*Rib_Width + 0.6). Default
    screws become standard M4x40, and the max stacking latch density
    assert now passes at defaults.
    - Stacking_Latch_Density=max now places latches at interior grid cell
    boundaries (superset of standard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
    [_tmp_probe.scad, rugged-box-library.scad]
2026-07-17 Remove stray temporary probe file
    [_tmp_probe.scad]
2026-07-18 Add removable level tray for bin layers
    A tray whose top copies the box floor baseplate and whose underside has
    simplified Gridfinity feet, registering on the box floor or on a layer
    of equal-height bins. Two fold-flat pull bails recessed into deepened
    wells at two edge cells lift the whole level out; folded, they stay
    below the bin seating plane so every cell stays usable. Fully printed:
    bails pivot on printed 3mm axle pins inserted from the tray edge faces,
    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
    [level-tray.scad]
2026-07-18 Add hex nut pocket option for attachment screws
    New Nut_Pockets option cuts DIN 934 hex nut pockets into the outward
    faces of the attachment ribs (latch, stacking latch, and both outer
    faces of the bottom hinge ribs) and enlarges all attachment screw holes
    to clearance fit. Screws clamp with nuts instead of thread-forming:
    hinge pins cannot rotate with the lid, plastic threads do not wear with
    reassembly, and cut threaded rod substitutes for screws. Stock screw
    lengths still work; the nut sits flush inside the pocket.
    Default off; geometry with the option disabled is unchanged (verified
    by STL vertex hash against the previous build).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
    [rugged-box-gridfinity.scad, rugged-box-library.scad, rugged-box.scad]
2026-07-18 Add axle sleeve option: short common screws, smooth bearings
    New Axle_Sleeves option replaces every long M4x40 through screw with a
    printed 8mm bearing sleeve spanning between the attachment ribs,
    retained by two short M4x12..20 screws driven into its bore from the
    rib outer faces. Rotating parts (latches, stacking latches, hinge
    tongue, handle) ride the smooth sleeve surface instead of screw
    threads, eliminating thread-on-plastic bearing contact; the sleeve is
    a replaceable wear part, and an 8mm round M4 brass standoff is a
    drop-in metal substitute. No screws longer than 20mm remain in the
    box. New axle_sleeve part renders the full sleeve set for the
    configured box.
    Rotating-bore diameters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
    [rugged-box-gridfinity.scad, rugged-box-library.scad, rugged-box.scad]
2026-07-18 Add split lid handle style: self-clamping X-arch on four pivots
    New Lid_Handle_Style=split option: two point-symmetric half-bails (one
    printed part, used twice) on parallel axes 18mm apart at the lid
    center. They fold inward past each other with arms interleaved into
    separate lanes, and rise to a self-clamping X-arch — under load, arm
    tension presses the grip bars together, so no latch is needed.
    Compared to the single bail: four M3 pivots halve the per-pivot cyclic
    carry load, the pocket is symmetric, ~9mm shorter and 1mm shallower
    (preserving more of the lid stacking grid), the box hangs level on
    every size including 2-unit-long lids, and the finger scoop is gone —
    the halves are rais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
    [rugged-box-gridfinity.scad, rugged-box-library.scad]
2026-07-19 Add silicone cord seal option
    New Lip_Seal_Type "silicone" with Silicone_Cord_Diameter (2..4 mm):
    a dovetail cord groove in the bottom lip. Depth is 0.75x the cord for
    up to ~25% face compression self-limited by lip contact; the 0.95x
    dovetail mouth snaps the cord in and retains it when open; the groove
    cross-section exceeds the cord area so the incompressible silicone can
    spread. The top part is unchanged. Required cord length is echoed in
    the BOM.
    [rugged-box-gridfinity.scad, rugged-box-library.scad, rugged-box.scad]
2026-07-19 Add showcase README with demo animation and hero renders
    Root README now presents the fork: demo video/GIF (one-turn overview,
    lid opening, transparent walls, two bin layers plus the removable level
    tray loading in, closing, stacking a second case with hardware focus,
    and the split X-arch handle raising and lifting the stack), three hero
    renders, and a feature overview linking to the full model docs. Media
    rendered from the actual parametric models (demo box 4x3x15U with split
    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
2026-07-20 Fix demo animation: latch direction, transparency, handle on lid
    - Stacking latch now animates from stowed (along the box side, matching
    the closed pose) down across the seam to latch the box below; it was
    inverted and appeared to unlatch during the stacking phase.
    - Opaque contents and hardware are declared before the translucent
    shell so preview transparency composites correctly while bins drop.
    - The split handle halves ride the lid frame (visible folded from the
    start and through opening/closing) instead of appearing after close.
